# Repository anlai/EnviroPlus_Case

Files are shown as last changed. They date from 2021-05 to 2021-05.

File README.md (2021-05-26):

# Enviro+ Case

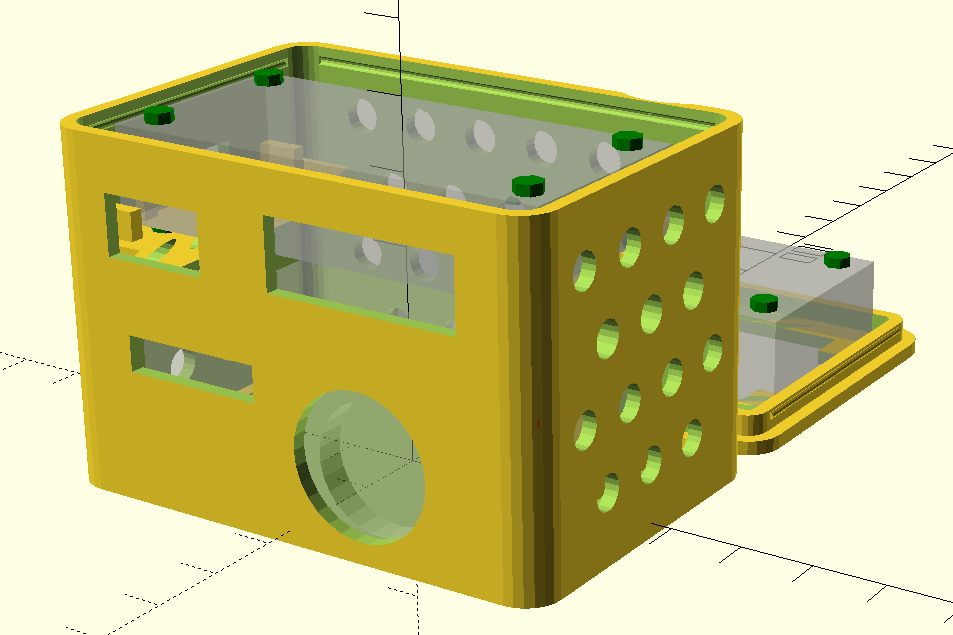
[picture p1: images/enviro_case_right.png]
Enviro Case


Case for an Enviro+ setup with PMS5003 particle sensor.  This case differs from other case designs because it doesn't require any screws or extra hardware to put the case together (just the standoffs for Pi HATs).  The interior of the case has supports to hold the particle sensor and the pi in place and the top is held in place by friction fit.

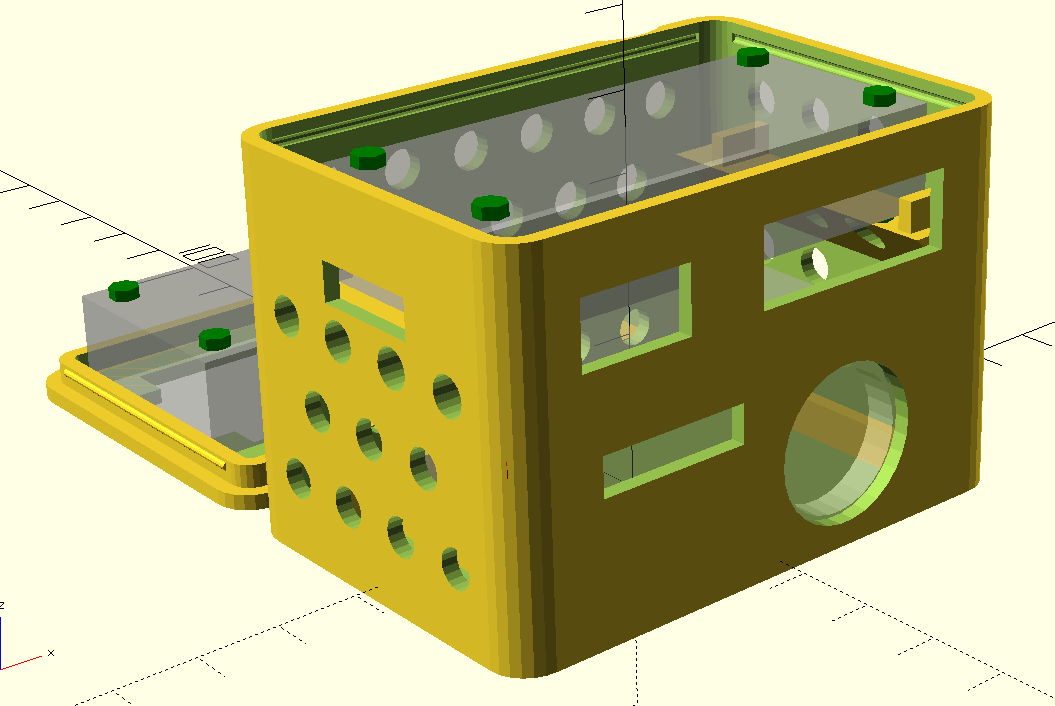
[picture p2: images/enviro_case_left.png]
Enviro Case (left)


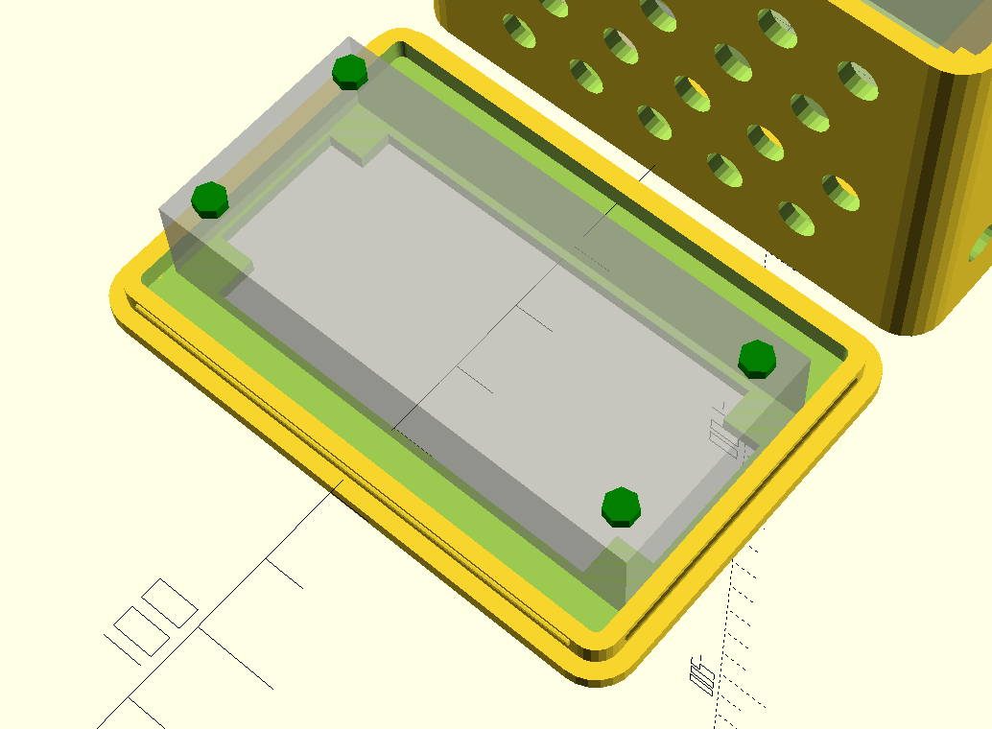
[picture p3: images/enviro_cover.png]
Enviro Cover


## Sensors Parts List

The case is designed to fit these specific pieces (including the specific height of the standoffs).

- Raspberry Pi Zero WH (with headers)
- Pimoroni Enviro+
- M2.5 Standoffs, [these ones](https://shop.pimoroni.com/products/brass-m2-5-standoffs-for-pi-hats-black-plated-pack-of-2)
- PMS5003 Particulate Matter Sensor (with cable)

## Customizer Prameters

- **opening_help** - Puts a notch in the case to make it easier to open
- **separator** - Not used except to judge the height of the case to the top of the cover
- **showComponents** - Show the placeholders to adjust placement (blocks for the Raspi and the PMS5003)
- **renderItems** - Which item to render, both, cover, or box

*note that the original dimension parameters have been hidden since they need to be locked on size for the rest of the features to be in the right spot

## Printing

The case was printed using an Ender 3 v2 with all stock hardware and Hatchbox Black 1.75mm PLA.  Export the scad file into an STL and slice with your favorite slicer.

## Original Design

The case design was based off of [this box with snap on cover by Inhumierer on Thingiverse](https://www.thingiverse.com/thing:2411898).  Dimensions, supports, and cut outs were added to the design.

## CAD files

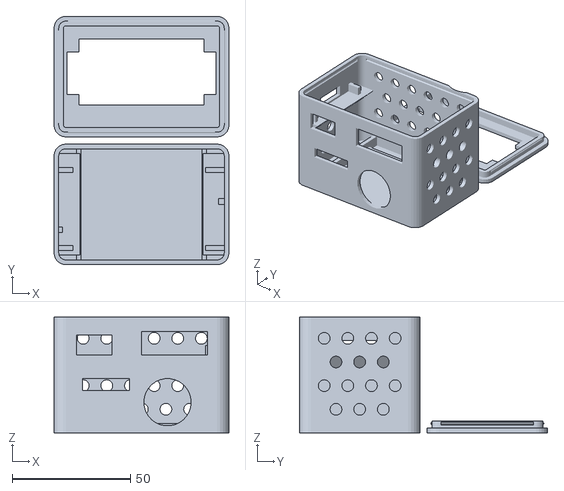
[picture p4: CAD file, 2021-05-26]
enviro_plus_case.stl
74.0 x 105.0 x 49.0

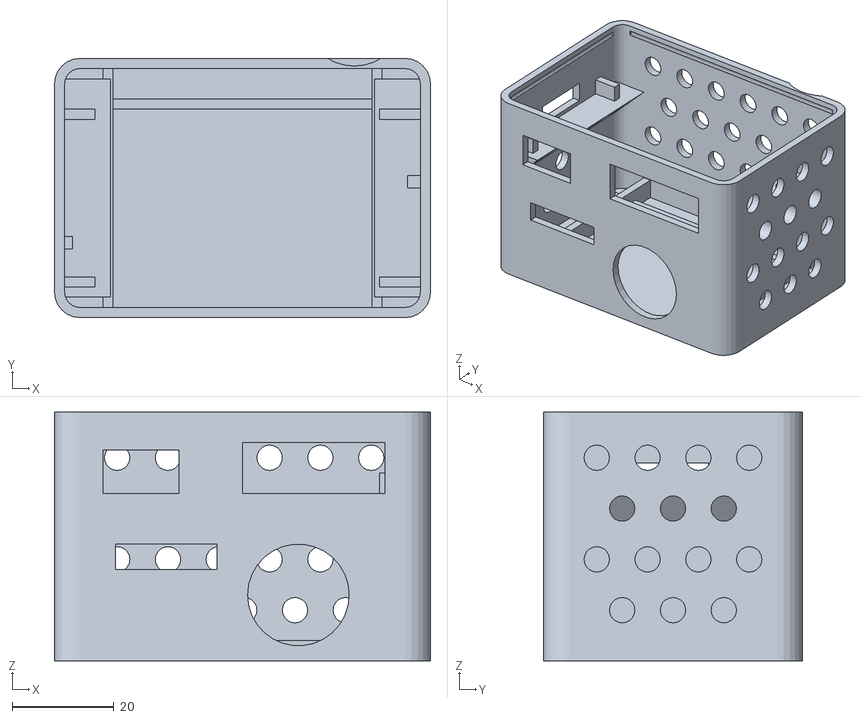
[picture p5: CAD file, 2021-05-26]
enviro_plus_case_only.stl
74.0 x 51.0 x 49.0

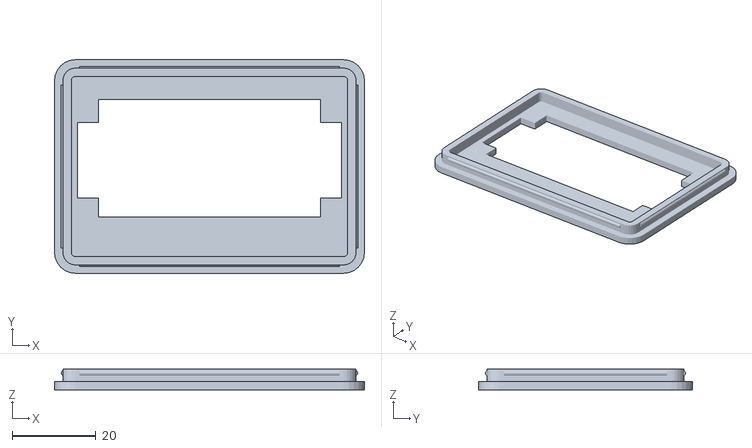
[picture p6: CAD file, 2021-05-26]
enviro_plus_cover_only.stl
74.0 x 51.0 x 5.00

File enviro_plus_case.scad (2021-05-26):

// V 1.2 Correction / hint from molotok3D, some minor fixes
// V 1.1- added opening helper and an optional separating wall

// Opening Help Gap
opening_help=true;	 // [true,false]

// Interior Divider (mm from on edge), 0 for none
separator=0;

// Show Components
showComponents=true; // [true,false]

// Render Cover
renderItems="both"; // [both,box,cover]

/* [Hidden] */
wi=70; // Width (inner size, in mm)
li=47; // Length (inner size, in mm)
h=47; // Height (inner size, in mm)
r=3; // Radius of the Rounded Corners
th=2; // wall thickness

e=0.01;
ri=(r>th)?r-th:e;	// needed for the cover - needs to be larger than 0 for proper results
l=li-2*r;
w=wi-2*r;

// particle sensor dimenions
particle_width=50;
particle_depth=38;  // 45 with the space for the cable out the back
particle_height=21;
particle_fan_diameter=18;

/** core objects **/

module box(){
    
	difference(){
		translate([0,0,-th])hull(){
			for (i=[[-w/2,-l/2],[-w/2,l/2],[w/2,-l/2],[w/2,l/2]]){
				translate(i)cylinder(r=r+th,h=h+th,$fn=8*r);
			}
		}
		hull(){
			for (i=[[-w/2,-l/2],[-w/2,l/2,],[w/2,-l/2],[w/2,l/2]]){
				translate(i)cylinder(r=r,h=h+1,$fn=8*r);
			}
		}
		translate([-w/2,l/2+r,h-2])rotate([0,90,0])cylinder(d=1.2,h=w,$fn=12);
		translate([-w/2,-l/2-r,h-2])rotate([0,90,0])cylinder(d=1.2,h=w,$fn=12);
		translate([w/2+r,l/2,h-2])rotate([90,0,0])cylinder(d=1.2,h=l,$fn=12);
		translate([-w/2-r,l/2,h-2])rotate([90,0,0])cylinder(d=1.2,h=l,$fn=12);

		// if you need some adjustment for the opening helper size or position,
		// this is the right place
		if (opening_help)translate([w/2-10,l/2+13.5,h-1.8])cylinder(d=20,h=10,$fn=32);
	}
	
    /* generate supports for the internal components */
    
    // particle sensor holders
    translate([0,-l/2-2*th,0]) {
        translate([25.5,0,0]) cube([th,li+th,2.5*th]);
        translate([-27.5,0,0]) cube([th,li+th,2.5*th]);
    }
    translate([-w/2-2*th,15.5,0]) cube([wi+th,th,th]);

    // lower supports for the pi
    translate([-w/2-2*th,-l/2-th+1,particle_height])
        rotate([90,0,90]) prism(li-2*th,10,10);

    translate([w/2+2*th,l/2+1,particle_height])
        rotate([90,0,270]) prism(li-2*th,10,10);

    // pi holders
    translate([w/2-5,0,particle_height+10]) {
        translate([0,-19.5,0]) cube([8,th,2*th]);
        translate([0,13.5,0]) cube([8,th,2*th]);
        translate([5.5,0,0]) cube([1.25*th,1.25*th,2*th]);

        //spacer to match the spacing with the top
        //color("red") translate([0,-23.5,0]) cube([6,6,6]);
    }
    translate([-w/2-5,0,particle_height+10]) {
        translate([0,-19.5,0]) cube([8,th,2*th]);
        translate([0,13.5,0]) cube([8,th,2*th]);

        translate([1,-12,0]) cube([1.25*th,1.25*th,2*th]);
    }

    // TODO: delete once done
    if (separator>0){
		translate([separator-wi/2,-li/2-e,-e])difference(){
			cube([th,li+2*e,h]);
			translate([-e,-e,h-3])cube([th+2*e,2*th+2+2*e,5]);
			translate([-e,e+li-2*th-2,h-3])cube([th+2+2*e,2*th+2+2*e,5]);
		}
	}
}

module cover(w,r,l){

    translate([0,0,-th])hull(){
        for (i=[[-w/2,-l/2],[-w/2,l/2],[w/2,-l/2],[w/2,l/2]]){
            translate(i)cylinder(r=r+th,h=th,$fn=8*r);
        }
    }

	difference(){
		translate([0,0,-th])hull(){
			for (i=[[-w/2,-l/2],[-w/2,l/2],[w/2,-l/2],[w/2,l/2]]){
				translate(i)cylinder(r=r,h=th+3,$fn=8*r);
			}
		}
		hull(){
			for (i=[[-w/2,-l/2],[-w/2,l/2],[w/2,-l/2],[w/2,l/2]]){
				if (r>th){
					translate(i)cylinder(r=r-th,h=3+2,$fn=8*r);
				}else{
					translate(i)cylinder(r=e,h=3+2,$fn=8*r);
				}
			}
		}
	}
	translate([-w/2+1,l/2+r-0.2,2])rotate([0,90,0])cylinder(d=1.2,h=w-2,$fn=12);
	translate([-w/2+1,-l/2-r+0.2,2])rotate([0,90,0])cylinder(d=1.2,h=w-2,$fn=12);
	translate([w/2+r-0.2,l/2-1,2])rotate([90,0,0])cylinder(d=1.2,h=l-2,$fn=12);
	translate([-w/2-r+0.2,l/2-1,2])rotate([90,0,0])cylinder(d=1.2,h=l-2,$fn=12);

}

module prism(l, w, h){
   polyhedron(
       points=[[0,0,0], [l,0,0], [l,w,0], [0,w,0], [0,w,h], [l,w,h]],
       faces=[[0,1,2,3],[5,4,3,2],[0,4,5,1],[0,3,4],[5,2,1]]
       );
}

module vent_grid(x,y,z,rows,maxPerRow) {
    vent_size=5;
    vent_spacing=vent_size*2;
    translate([x,y,z]) {
        rotate([90,0,0]) {
            for (row = [0:rows-1]) {
                ventsInRow = row % 2 == 0 ? maxPerRow : maxPerRow-1;
                initialOffset = row %2 == 0 ? 0 : -vent_size;
                offset=row*vent_spacing;

                translate([initialOffset,-offset,0])
                    for(i = [0:ventsInRow])
                        translate([-(i*vent_spacing+th),0,0]) cylinder(d=vent_size, h=20,$fn=20);

            }
        }
    }
}

/** end core objects **/

/** derived objects **/

module box_raspi(){
    difference(){
        box();
        // align on the primary edge
        translate([0,-li/2-(2*th),0]) {
            // usb ports
            translate([wi/8-7,0,0])
                cube([28,10,h+th]);
            
            // hdmi
            translate([-wi/2+7,0,0])
                cube([16,10,h/2]);
        
        }
        
        // sd card
        translate([-wi/2-(2*th),-5,0])
            cube([10,14,7]);

    }
}

module raspi_cover_holder() {
    w=64;
    r=3;
    l=29;
    cover(w,r,l);
}

module top_hole() {
    x_opening=63;
    y_opening=28;

    translate([-w/2+5.5,-l/2+8.5,-20]) cube([x_opening-10,y_opening,100]);
    translate([-w/2+.5,-l/2+13,-20]) cube([x_opening,y_opening-10,100]);
}

/** derived objects **/

/** fit objects **/

module raspi() {
    raspi_width=65;
    raspi_depth=30;
    raspi_height=13;
    raspi_height_withscres=16;
    raspi_screw_diameter=4;
    raspi_screw_off_edge=2;
    
    cube([raspi_width,raspi_depth,raspi_height]);
    
    color("green") {
        
        // calculate x-y offset values
        offset1 = raspi_screw_off_edge+2;
        offset2 = raspi_depth-(offset1);
        offset3 = raspi_width-(offset1);
        
        screw_height=1.5;
        
        // top side screws
        translate([offset1,offset1,raspi_height]) {
            cylinder(h=screw_height,d=raspi_screw_diameter);
        }
        
        translate([offset1,offset2,raspi_height]) {
            cylinder(h=screw_height,d=raspi_screw_diameter);
        }
        
        translate([offset3,offset1,raspi_height]){
            cylinder(h=screw_height,d=raspi_screw_diameter);
        }
        
        translate([offset3,offset2,raspi_height]){
            cylinder(h=screw_height,d=raspi_screw_diameter);
        }
        
        // bottom side screws
        translate([offset1,offset1,-screw_height]) {
            cylinder(h=screw_height,d=raspi_screw_diameter);
        }
        
        translate([offset1,offset2,-screw_height]) {
            cylinder(h=screw_height,d=raspi_screw_diameter);
        }
        
        translate([offset3,offset1,-screw_height]){
            cylinder(h=screw_height,d=raspi_screw_diameter);
        }
        
        translate([offset3,offset2,-screw_height]){
            cylinder(h=screw_height,d=raspi_screw_diameter);
        }      
        
    }
    
}

module particle_sensor() {
    difference(){
        cube([particle_width,particle_depth, particle_height]);

        // hole that represents the fan intake
        translate([37,4,10])
            rotate([90,0,0]) 
                cylinder(d=particle_fan_diameter,h=5);
    }

    // cable sticks out starting at 9mm from the bottom and 8mm from the top
    // cable opening is 4mm high
    // cable needs 7mm out the back
    // opening is 17mm wide
    translate([27,particle_depth,9]) cube([17,7,4]);
}

/** end fit objects **/

/** command calls **/

if (renderItems == "both" || renderItems == "box")
    difference() {
        box();

        // particle sensor cut out
        translate([particle_fan_diameter/2+2,-20,particle_fan_diameter/2+2])
                rotate([90,0,0]) cylinder(d=particle_fan_diameter+2,h=10);

        // particle sensor, dot openings
        translate([-25,-30,particle_height-5]) cube([20,10,5]);

        // raspi -- usb ports
        translate([0,-30,particle_height+10]) {
            cube([28,10,10]);
        }

        // raspi -- hdmi
        translate([-27.5,-30,particle_height+10]) {
            cube([15,10,8.5]);
        }

        // raspi -- sd card
        translate([-40,-8, particle_height+11]) {
            cube([10,15,5]);
        }

        // vent holes
        vent_grid(wi/3+4,30,particle_height+17,4,5);

        rotate([0,0,90])
        translate([17,-20,0])
        vent_grid(0,0,particle_height+17,4,3);

        rotate([0,0,90])
        translate([17,40,-10])
        vent_grid(0,0,particle_height+17,3,3);
    }

if (renderItems == "both" || renderItems == "cover")
    translate([0,li+3+2*th,0]) {
        difference() {
            cover(w,r,l);
            top_hole();
        }

        // difference() {
        //     translate([0,th,0]) raspi_cover_holder();
        //     top_hole();
        // }
    }
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

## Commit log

2021-05-24 particle back, lower to th. raspi usb shift 2mm
    [enviro_plus_case_v2.scad]
2021-05-26 removed the bar preventing sensor from fitting
    [enviro_plus_case_v2.scad]
2021-05-26 updated parameters
    [enviro_plus_case_v2.scad]
2021-05-26 renamed scad file
    [enviro_plus_case.scad]
2021-05-26 stl files
    [enviro_plus_case.stl, enviro_plus_case_only.stl, enviro_plus_cover_only.stl]
